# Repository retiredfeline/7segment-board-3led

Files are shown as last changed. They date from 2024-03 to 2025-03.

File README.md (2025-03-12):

# 7 segment 2 digit board with 3 LEDs per segment

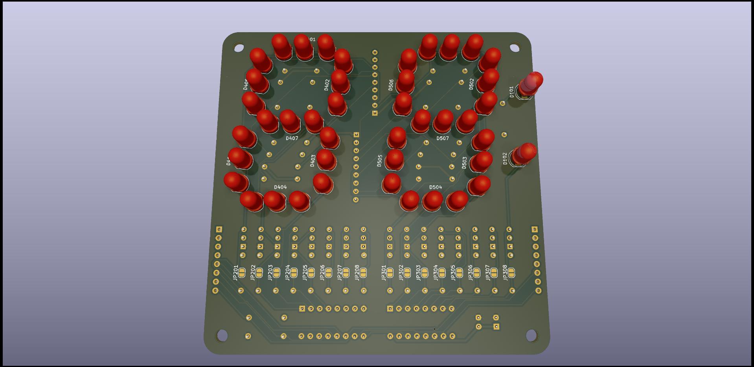
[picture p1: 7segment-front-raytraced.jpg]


These are the design files for a 7 segment board for [Ancient 12 hour display](https://hackaday.io/project/184942-ancient-12-hour-display) but which can be used with modern 5mm LEDs.

## Versioning

Release March 2025

## Notes

Most components are installed on the back side and the LEDs are installed on the front side.

The board is designed to be cascadable by using the versatile 74HC595 shift register which only requires 3 lines to drive, plus power. Two boards stiched together with jumpers form 4 digits. You can see there is room for lots of driver transistors and base resistors. Those are only needed for these old LEDs due to their inefficiency and higher current draw. Modern LEDs with current draw 6 mA or less can be driven directly from the 74HC595 using the solder jumpers to bypass the transistors. The LED current limiting resistor is a resistor network which reduces component count but discrete resistors can be used instead if preferred. Remember that VDC - 3 x LED voltage drop should not exceed VCC.

## Authors

* **Ken Yap**

## License

See the [LICENSE](LICENSE.md) file for license rights and limitations (MIT).

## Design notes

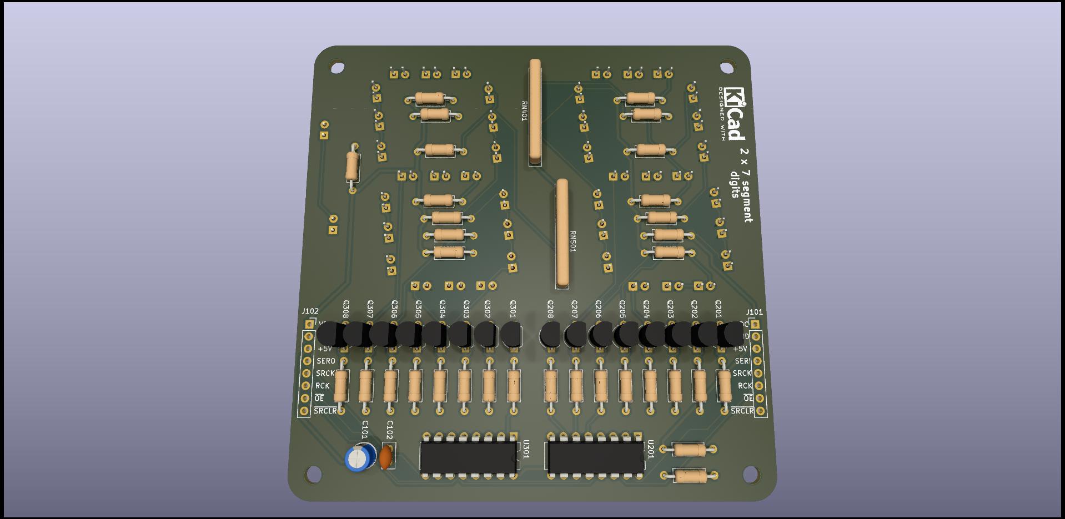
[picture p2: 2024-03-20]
7segment-back-raytraced.jpg

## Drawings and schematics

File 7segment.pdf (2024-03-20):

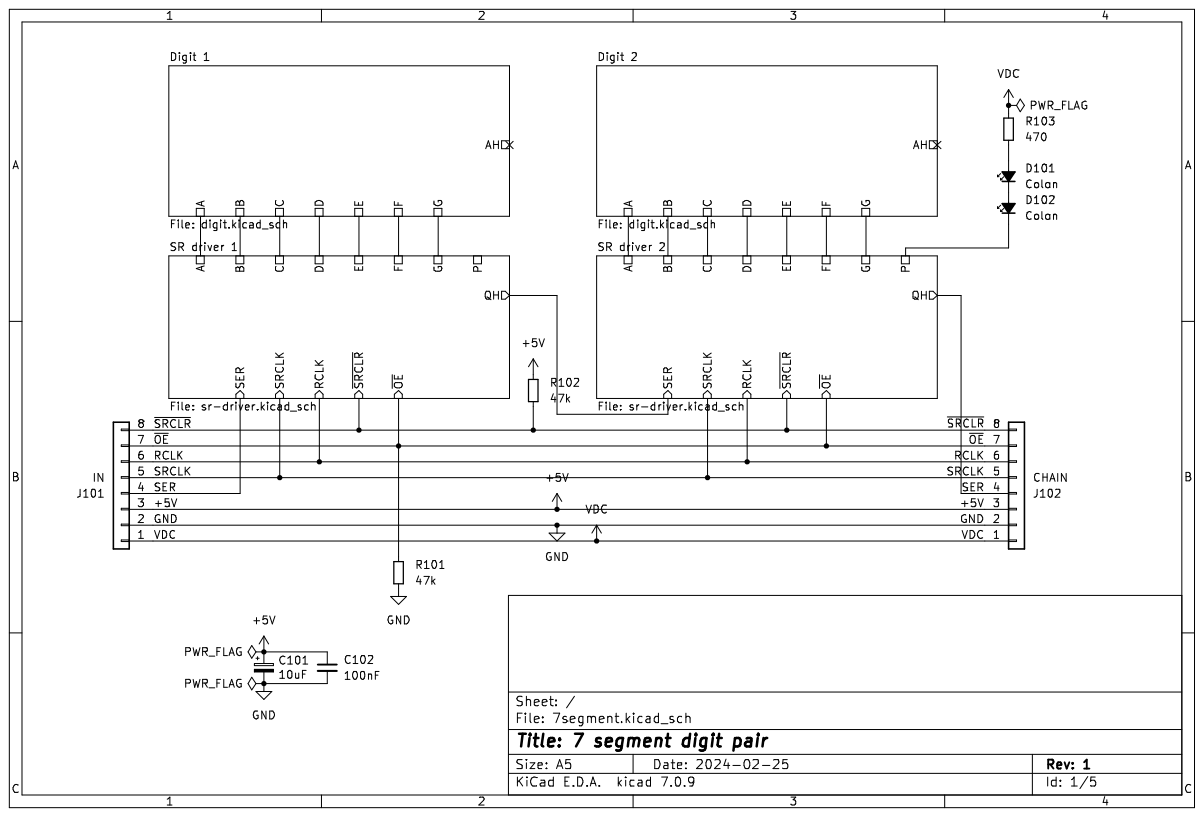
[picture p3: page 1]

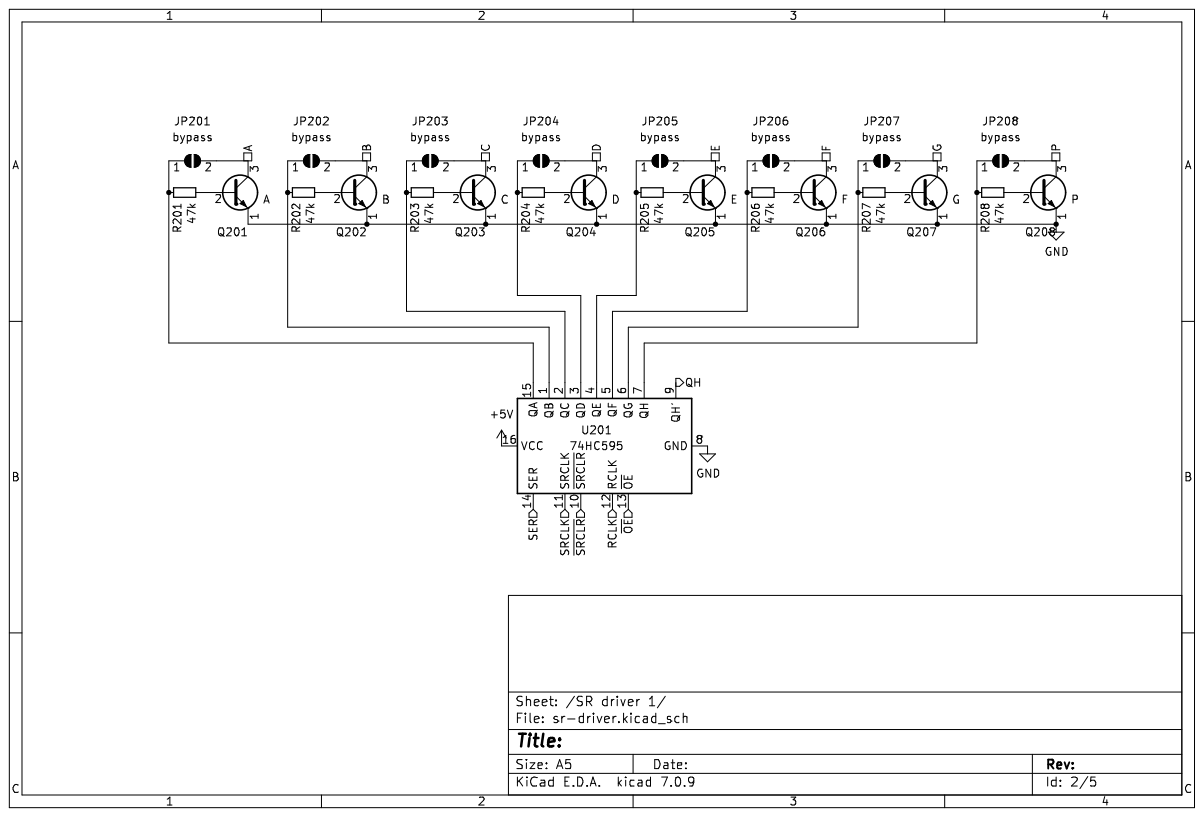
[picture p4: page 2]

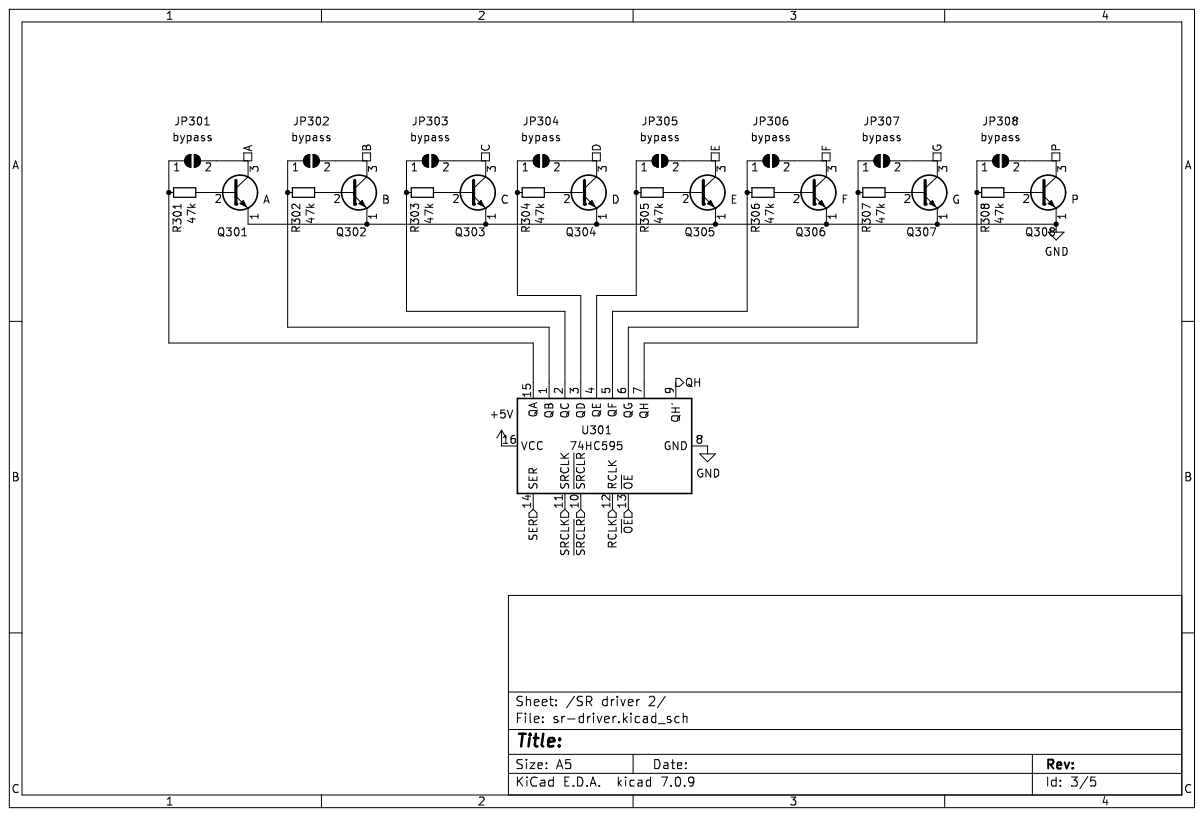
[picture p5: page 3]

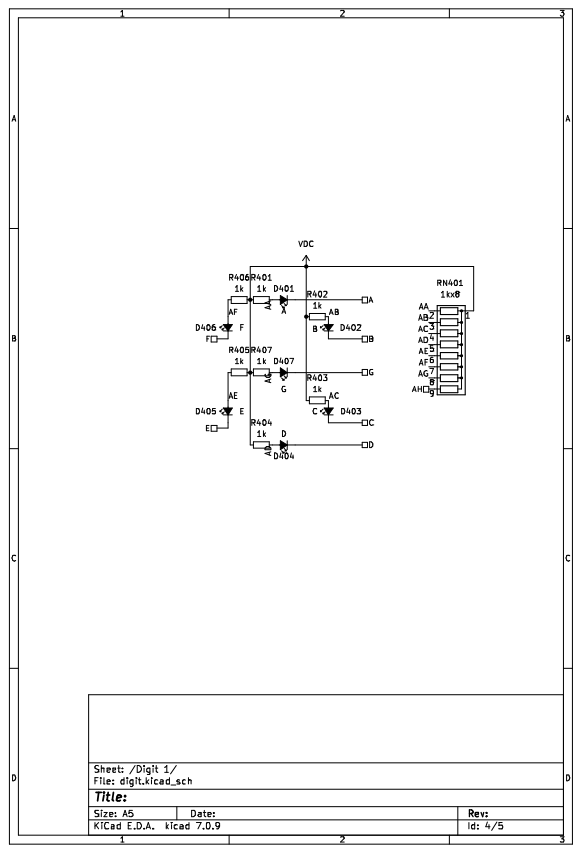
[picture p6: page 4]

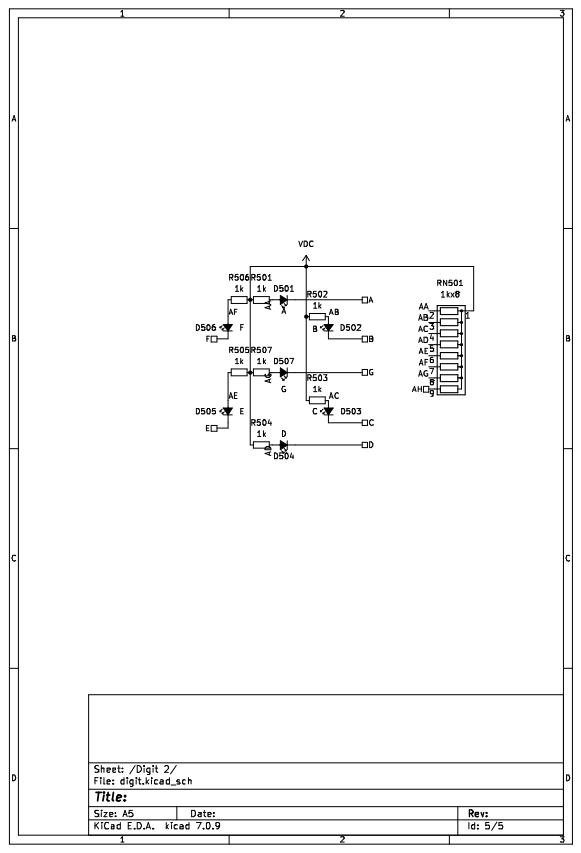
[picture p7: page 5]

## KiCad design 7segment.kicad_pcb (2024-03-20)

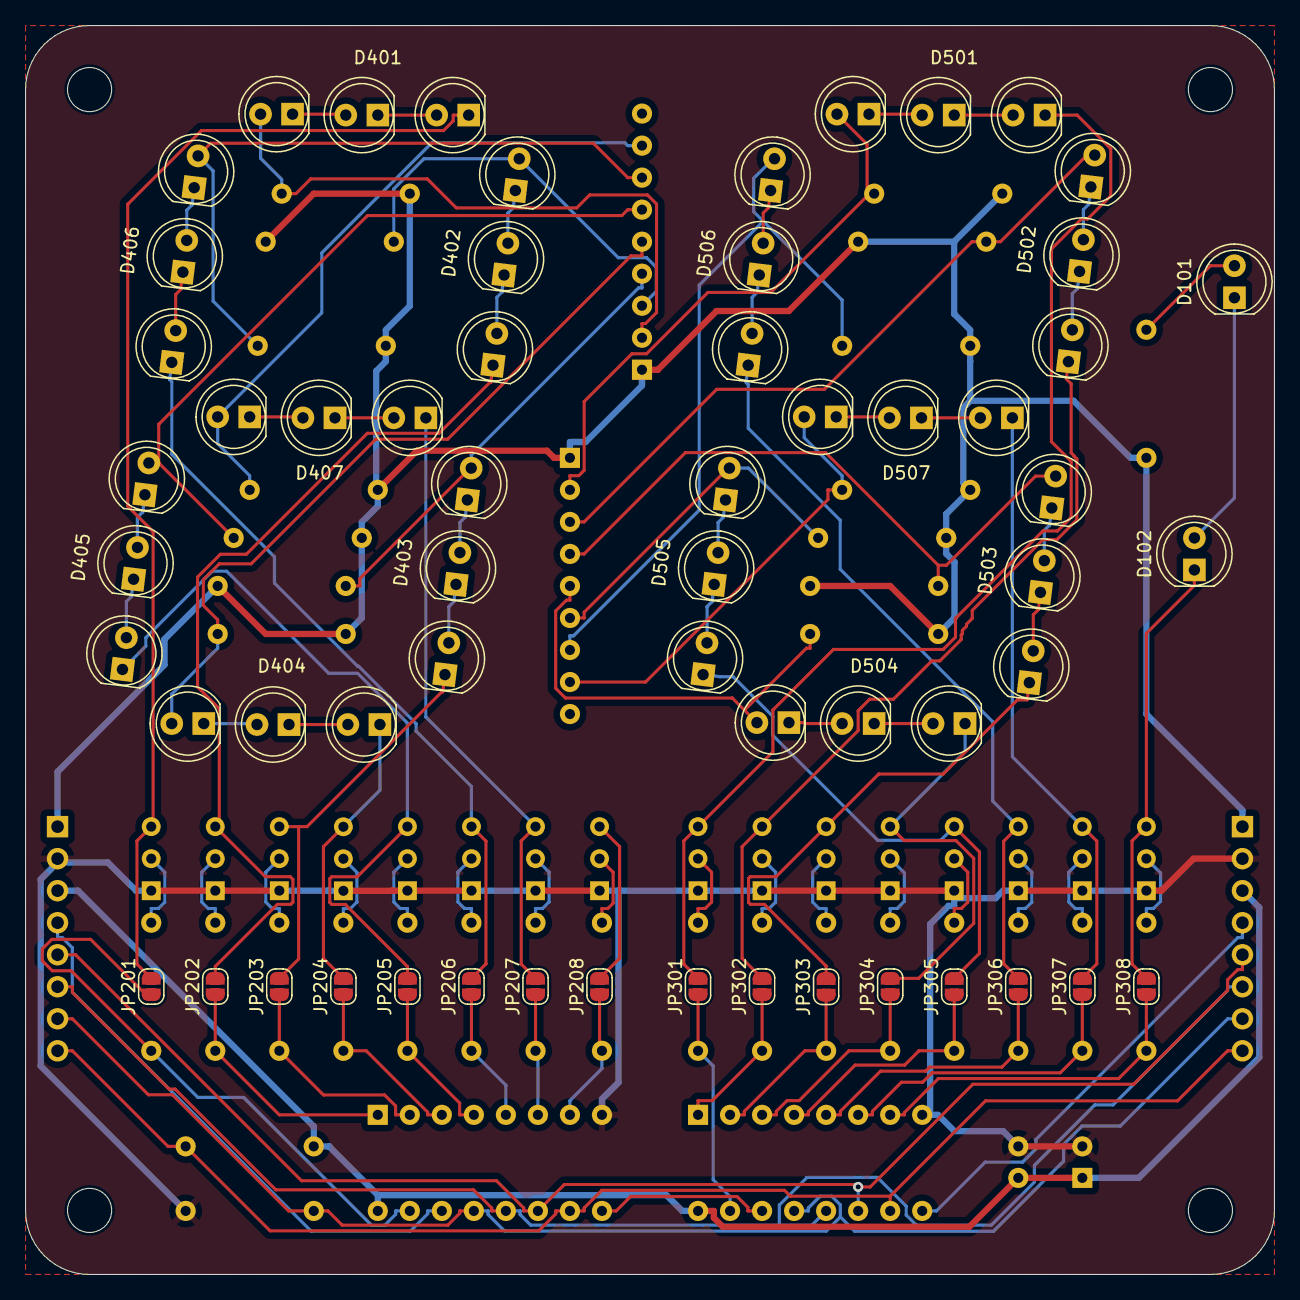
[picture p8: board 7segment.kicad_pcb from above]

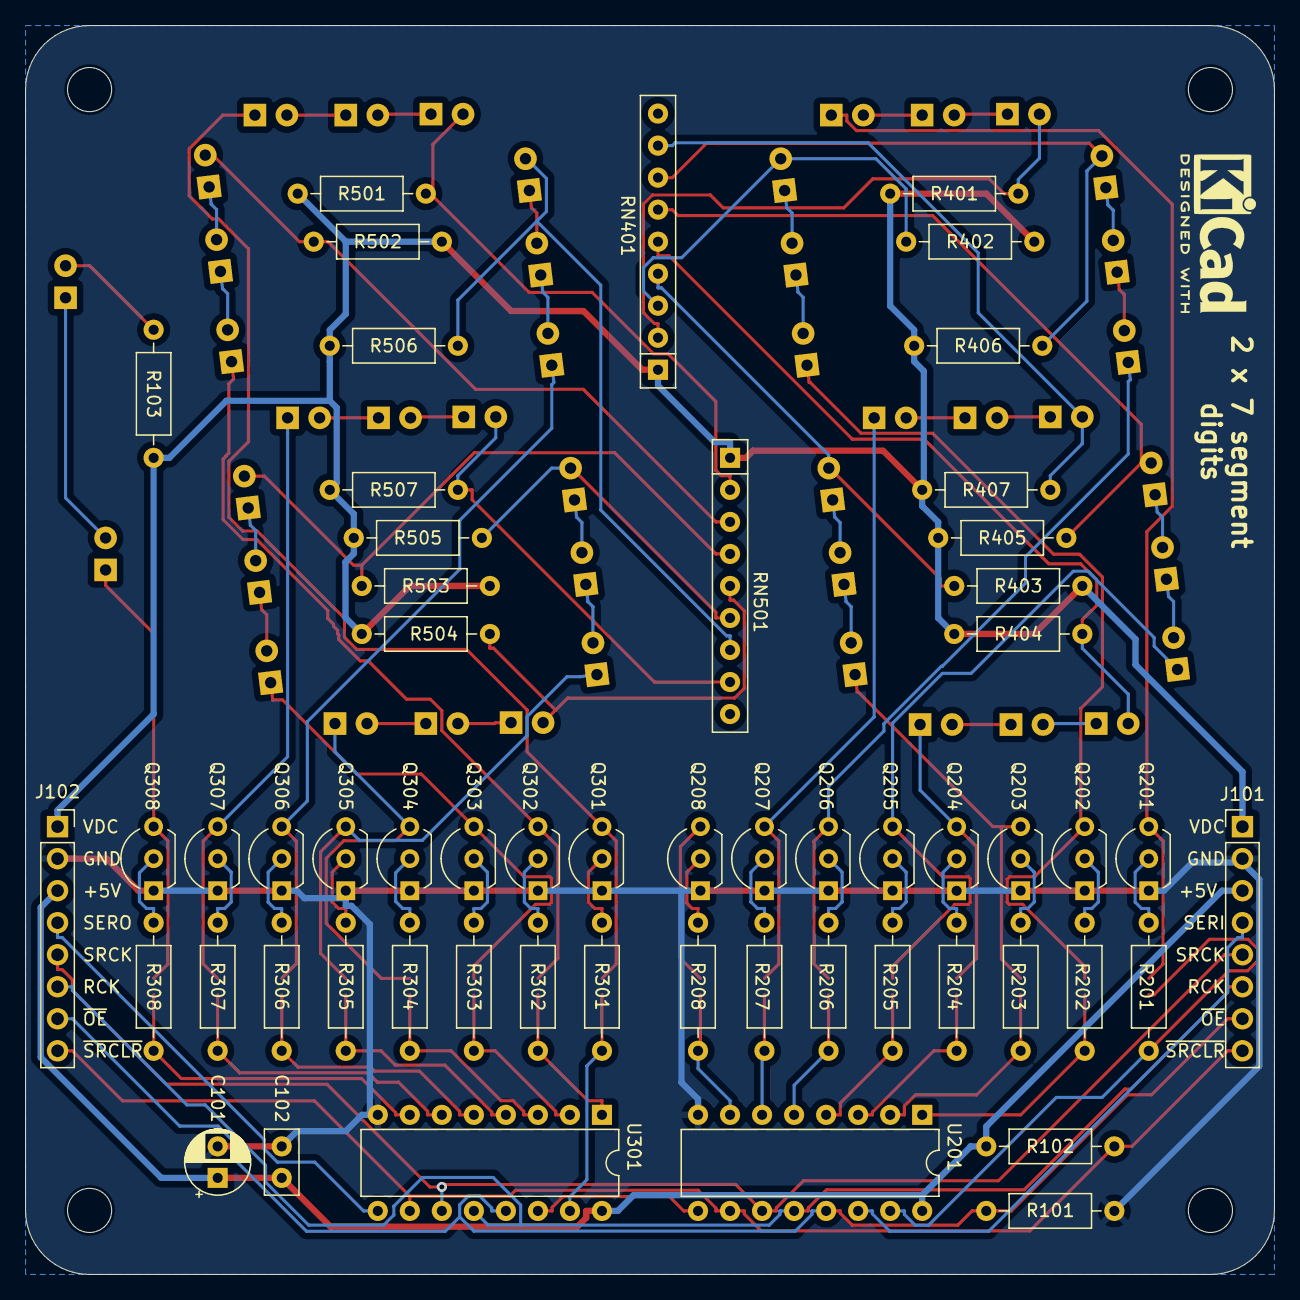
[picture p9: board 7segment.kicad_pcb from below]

Board: 2 copper layers, 99.1 x 99.1 mm, 93 parts (57 on the bottom side), 74 nets.

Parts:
C101: 10uF; CP_Radial_D5.0mm_P2.50mm
C102: 100nF; C_Disc_D5.0mm_W2.5mm_P2.50mm
D101, D102: Colon; LED_D5.0mm
D401, D501: A; LED_D5.0mmx3
D402, D502: B; LED_D5.0mmx3
D403, D503: C; LED_D5.0mmx3
D404, D504: D; LED_D5.0mmx3
D405, D505: E; LED_D5.0mmx3
D406, D506: F; LED_D5.0mmx3
D407, D507: G; LED_D5.0mmx3
H1, H2, H3, H4: MountingHole; MountingHole_3.5mm
J101: IN; PinHeader_1x08_P2.54mm_Vertical
J102: CHAIN; PinSocket_1x08_P2.54mm_Vertical
JP201, JP202, JP203, JP204, JP205, JP206, JP207, JP208, JP301, JP302, JP303, JP304, JP305, JP306, JP307, JP308: bypass; SolderJumper-2_P1.3mm_Open_RoundedPad1.0x1.5mm
Q201, Q301: A; TO-92L_Inline_Wide
Q202, Q302: B; TO-92L_Inline_Wide
Q203, Q303: C; TO-92L_Inline_Wide
Q204, Q304: D; TO-92L_Inline_Wide
Q205, Q305: E; TO-92L_Inline_Wide
Q206, Q306: F; TO-92L_Inline_Wide
Q207, Q307: G; TO-92L_Inline_Wide
Q208, Q308: P; TO-92L_Inline_Wide
R101, R102, R201, R202, R203, R204, R205, R206, R207, R208, R301, R302, R303, R304, R305, R306, R307, R308: 47k; R_Axial_DIN0207_L6.3mm_D2.5mm_P10.16mm_Horizontal
R103: 2k2; R_Axial_DIN0207_L6.3mm_D2.5mm_P10.16mm_Horizontal
R401, R402, R403, R404, R405, R406, R407, R501, R502, R503, R504, R505, R506, R507: 1k; R_Axial_DIN0207_L6.3mm_D2.5mm_P10.16mm_Horizontal
RN401, RN501: 1kx8; R_Array_SIP9
U201, U301: 74HC595; DIP-16_W7.62mm

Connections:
+5V: C101.1, C102.1, J101.3, J102.3, R102.2, U201.16 (VCC), U301.16 (VCC)
/Digit 1/A: D401.1 (K), JP201.2 (B), Q201.3 (C)
/Digit 1/AA: D401.2 (A), R401.2, RN401.2 (R1)
/Digit 1/AB: D402.2 (A), R402.2, RN401.3 (R2)
/Digit 1/AC: D403.2 (A), R403.2, RN401.4 (R3)
/Digit 1/AD: D404.2 (A), R404.2, RN401.5 (R4)
/Digit 1/AE: D405.2 (A), R405.1, RN401.6 (R5)
/Digit 1/AF: D406.2 (A), R406.1, RN401.7 (R6)
/Digit 1/AG: D407.2 (A), R407.2, RN401.8 (R7)
/Digit 1/B: D402.1 (K), JP202.2 (B), Q202.3 (C)
/Digit 1/C: D403.1 (K), JP203.2 (B), Q203.3 (C)
/Digit 1/D: D404.1 (K), JP204.2 (B), Q204.3 (C)
/Digit 1/E: D405.1 (K), JP205.2 (B), Q205.3 (C)
/Digit 1/F: D406.1 (K), JP206.2 (B), Q206.3 (C)
/Digit 1/G: D407.1 (K), JP207.2 (B), Q207.3 (C)
/Digit 2/A: D501.1 (K), JP301.2 (B), Q301.3 (C)
/Digit 2/AA: D501.2 (A), R501.2, RN501.2 (R1)
/Digit 2/AB: D502.2 (A), R502.2, RN501.3 (R2)
/Digit 2/AC: D503.2 (A), R503.2, RN501.4 (R3)
/Digit 2/AD: D504.2 (A), R504.2, RN501.5 (R4)
/Digit 2/AE: D505.2 (A), R505.1, RN501.6 (R5)
/Digit 2/AF: D506.2 (A), R506.1, RN501.7 (R6)
/Digit 2/AG: D507.2 (A), R507.2, RN501.8 (R7)
/Digit 2/B: D502.1 (K), JP302.2 (B), Q302.3 (C)
/Digit 2/C: D503.1 (K), JP303.2 (B), Q303.3 (C)
/Digit 2/D: D504.1 (K), JP304.2 (B), Q304.3 (C)
/Digit 2/E: D505.1 (K), JP305.2 (B), Q305.3 (C)
/Digit 2/F: D506.1 (K), JP306.2 (B), Q306.3 (C)
/Digit 2/G: D507.1 (K), JP307.2 (B), Q307.3 (C)
/SR driver 1/P: JP208.2 (B), Q208.3 (C)
/SR driver 1/QH: U201.9 (QH'), U301.14 (SER)
/SR driver 1/RCLK: J101.6, J102.6, U201.12 (RCLK), U301.12 (RCLK)
/SR driver 1/SER: J101.4, U201.14 (SER)
/SR driver 1/SRCLK: J101.5, J102.5, U201.11 (SRCLK), U301.11 (SRCLK)
/SR driver 1/~OE: J101.7, J102.7, R101.2, U201.13 (~OE), U301.13 (~OE)
/SR driver 1/~SRCLR: J101.8, J102.8, R102.1, U201.10 (~SRCLR), U301.10 (~SRCLR)
/SR driver 2/P: D102.1 (K), JP308.2 (B), Q308.3 (C)
/SR driver 2/QH: J102.4, U301.9 (QH')
GND: C101.2, C102.2, J101.2, J102.2, Q201.1 (E), Q202.1 (E), Q203.1 (E), Q204.1 (E), Q205.1 (E), Q206.1 (E), Q207.1 (E), Q208.1 (E), Q301.1 (E), Q302.1 (E), Q303.1 (E), Q304.1 (E), Q305.1 (E), Q306.1 (E), Q307.1 (E), Q308.1 (E), R101.1, U201.8 (GND), U301.8 (GND)
unnamed: D101.2 (A), R103.1
unnamed: D101.1 (K), D102.2 (A)
unnamed: JP201.1 (A), R201.1, U201.15 (QA)
unnamed: JP202.1 (A), R202.1, U201.1 (QB)
unnamed: JP203.1 (A), R203.1, U201.2 (QC)
unnamed: JP204.1 (A), R204.1, U201.3 (QD)
unnamed: JP205.1 (A), R205.1, U201.4 (QE)
unnamed: JP206.1 (A), R206.1, U201.5 (QF)
unnamed: JP207.1 (A), R207.1, U201.6 (QG)
unnamed: JP208.1 (A), R208.1, U201.7 (QH)
unnamed: JP301.1 (A), R301.1, U301.15 (QA)
unnamed: JP302.1 (A), R302.1, U301.1 (QB)
unnamed: JP303.1 (A), R303.1, U301.2 (QC)
unnamed: JP304.1 (A), R304.1, U301.3 (QD)
unnamed: JP305.1 (A), R305.1, U301.4 (QE)
unnamed: JP306.1 (A), R306.1, U301.5 (QF)
unnamed: JP307.1 (A), R307.1, U301.6 (QG)
unnamed: JP308.1 (A), R308.1, U301.7 (QH)
unnamed: Q201.2 (B), R201.2
unnamed: Q202.2 (B), R202.2
unnamed: Q203.2 (B), R203.2
unnamed: Q204.2 (B), R204.2
unnamed: Q205.2 (B), R205.2
unnamed: Q206.2 (B), R206.2
unnamed: Q207.2 (B), R207.2
unnamed: Q208.2 (B), R208.2
unnamed: Q301.2 (B), R301.2
unnamed: Q302.2 (B), R302.2
unnamed: Q303.2 (B), R303.2
unnamed: Q304.2 (B), R304.2
unnamed: Q305.2 (B), R305.2
unnamed: Q306.2 (B), R306.2
unnamed: Q307.2 (B), R307.2
unnamed: Q308.2 (B), R308.2
VDC: J101.1, J102.1, R103.2, R401.1, R402.1, R403.1, R404.1, R405.2, R406.2, R407.1, R501.1, R502.1, R503.1, R504.1, R505.2, R506.2, R507.1, RN401.1 (common), RN501.1 (common)

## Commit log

2024-03-20 First version
    [7segment.kicad_pcb, 7segment.kicad_sch, digit.kicad_sch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]
2025-03-12 Add gerbers
    [7segment-B_Cu.gbl, 7segment-B_Mask.gbs, 7segment-B_Silkscreen.gbo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]
